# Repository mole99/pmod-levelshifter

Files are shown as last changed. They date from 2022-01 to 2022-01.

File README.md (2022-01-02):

# pmod-levelshifter
A bidirectional levelshifter designed in KiCad to control higher voltages on an FPGA.

Access the interactive BOM [here](https://htmlpreview.github.io/?https://github.com/mole99/pmod-levelshifter/blob/main/ibom/ibom.html).

I designed this board to interface a keyboard over a PS/2 port. The logic level of the keyboard is 5V whereas the FPGAs IOs run at 3.3V. The `pmod-levelshifter` relays a signal from the HV side to the LV side and vice versa. When no side is driven, the lines are pulled high. 8 IOs are supported.

# Screenshots

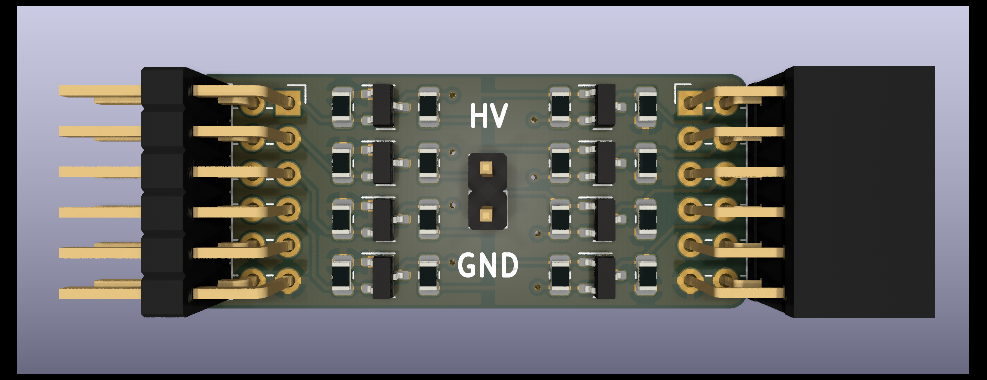
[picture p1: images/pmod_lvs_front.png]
Front Image


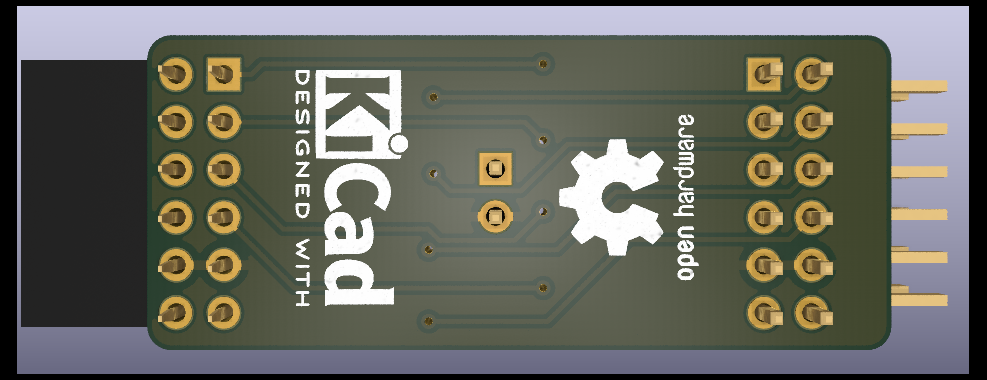
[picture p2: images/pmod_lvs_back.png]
Back Image


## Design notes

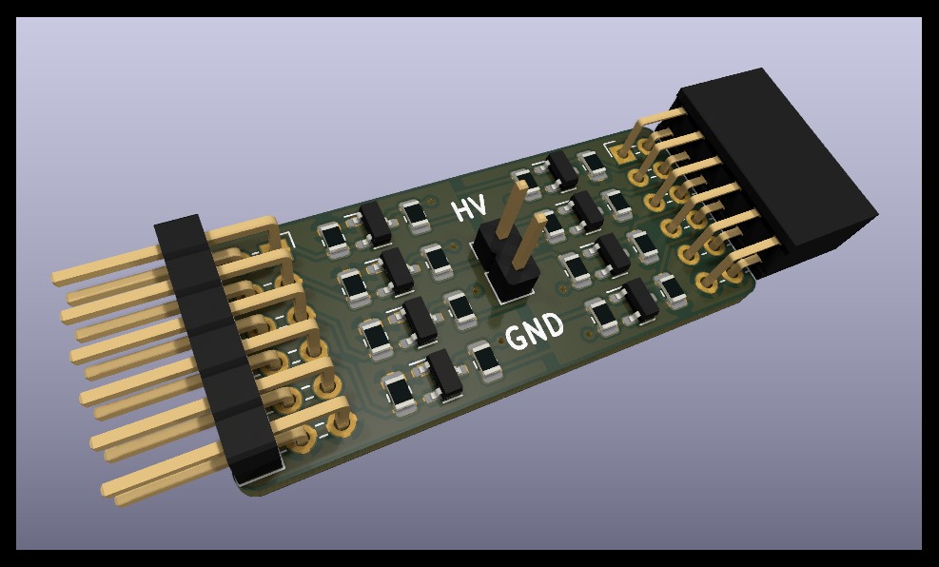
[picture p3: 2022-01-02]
images/pmod_lvs.png

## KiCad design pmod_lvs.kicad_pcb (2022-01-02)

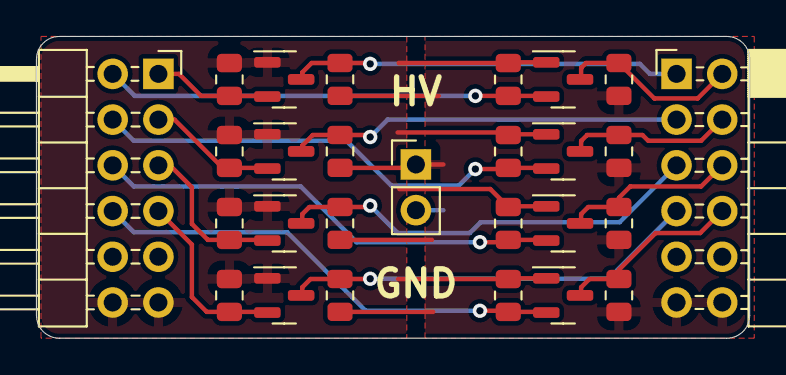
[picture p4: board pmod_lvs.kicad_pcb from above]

Board: 2 copper layers, 39.6 x 16.8 mm, 27 parts (0 on the bottom side), 19 nets.

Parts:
J1: PMOD_Socket; PMODSocket_2x06_P2.54mm_Horizontal
J2: PMOD_Header; PMODHeader_2x06_P2.54mm_Horizontal
J3: HV_connector; PinHeader_1x02_P2.54mm_Vertical
Q1, Q2, Q3, Q4, Q5, Q6, Q7, Q8: BSS138; SOT-23
R1, R2, R3, R4, R5, R6, R7, R8, R9, R10, R11, R12, R13, R14, R15, R16: 10k; R_0805_2012Metric

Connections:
+3V3: J2.6, J2.12, Q1.1 (G), Q2.1 (G), Q3.1 (G), Q4.1 (G), Q5.1 (G), Q6.1 (G), Q7.1 (G), Q8.1 (G), R1.1, R3.1, R5.1, R7.1, R9.1, R11.1, R13.1, R15.1
+5V: J1.6, J1.12, J3.1, R2.1, R4.1, R6.1, R8.1, R10.1, R12.1, R14.1, R16.1
GND: J1.5, J1.11, J2.5, J2.11, J3.2
HV0: J1.1, Q1.3 (D), R2.2
HV1: J1.2, Q2.3 (D), R4.2
HV2: J1.3, Q3.3 (D), R6.2
HV3: J1.4, Q4.3 (D), R8.2
HV4: J1.7, Q5.3 (D), R10.2
HV5: J1.8, Q6.3 (D), R12.2
HV6: J1.9, Q7.3 (D), R14.2
HV7: J1.10, Q8.3 (D), R16.2
LV0: J2.1, Q1.2 (S), R1.2
LV1: J2.2, Q2.2 (S), R3.2
LV2: J2.3, Q3.2 (S), R5.2
LV3: J2.4, Q4.2 (S), R7.2
LV4: J2.7, Q5.2 (S), R9.2
LV5: J2.8, Q6.2 (S), R11.2
LV6: J2.9, Q7.2 (S), R13.2
LV7: J2.10, Q8.2 (S), R15.2

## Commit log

2021-12-30 Populate project
    [lvlshifter.sch, pmod_lvs.kicad_pcb, pmod_lvs.sch]
2022-01-02 Migrate to KiCad 6
    [lvlshifter.kicad_sch, lvlshifter.sch, pmod_lvs.kicad_pcb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]
2022-01-02 Add IBOM
    [lvlshifter.kicad_sch, pmod_lvs.kicad_pcb, pmod_lvs.kicad_sch]
